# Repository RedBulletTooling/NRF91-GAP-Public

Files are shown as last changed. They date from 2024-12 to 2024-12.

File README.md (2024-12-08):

This is a project by Matthijs Vogel and Luc Pluimakers.

# Concept

NRF91 General Attack Platform, or GAP for short. The goal of the GAP module was to create a modular base from which we could design various types of listening devices. It serves as the central brain and communications hub, as well as the module that regulates power, eliminating the need for a complex PSU per purpose. We have decided to release this design to the public, as there is no benefit in keeping it private, and we believe it can add value to the public space.

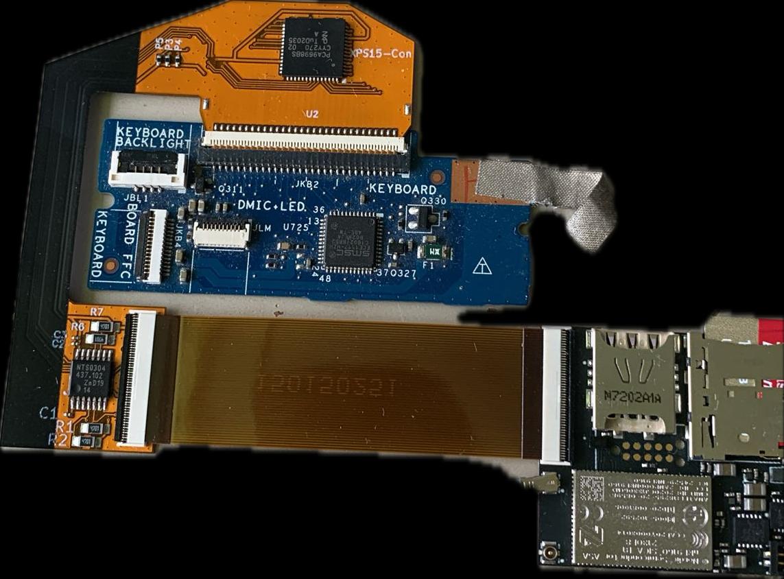
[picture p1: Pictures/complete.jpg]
complete


## NRF91GAP

The board itself. When designing it, the decision was made to make it thin—really thin. This is because most devices and locations have enough tolerance to hide something as long as it's thin enough. With this design, we achieved a thickness of 1.5mm. We used special LDOs (Low Dropout Regulators) with a wide operating range (20V to 1.8V)—one for powering the NRF91 and another for powering the external board, both outputting 5V. This way, it can be implemented in a car or connected directly to a laptop battery, making it an always-on system, regardless of whether the host machine is turned off. Perfect for pre-boot DMA injection! Almost all of the I/O of the NRF91 is directly connected to the ribbon cable, and they can be left floating if not needed. It uses a Tag-Connect cable for programming. It's a cool concept, and we hope some of you find a use for it!

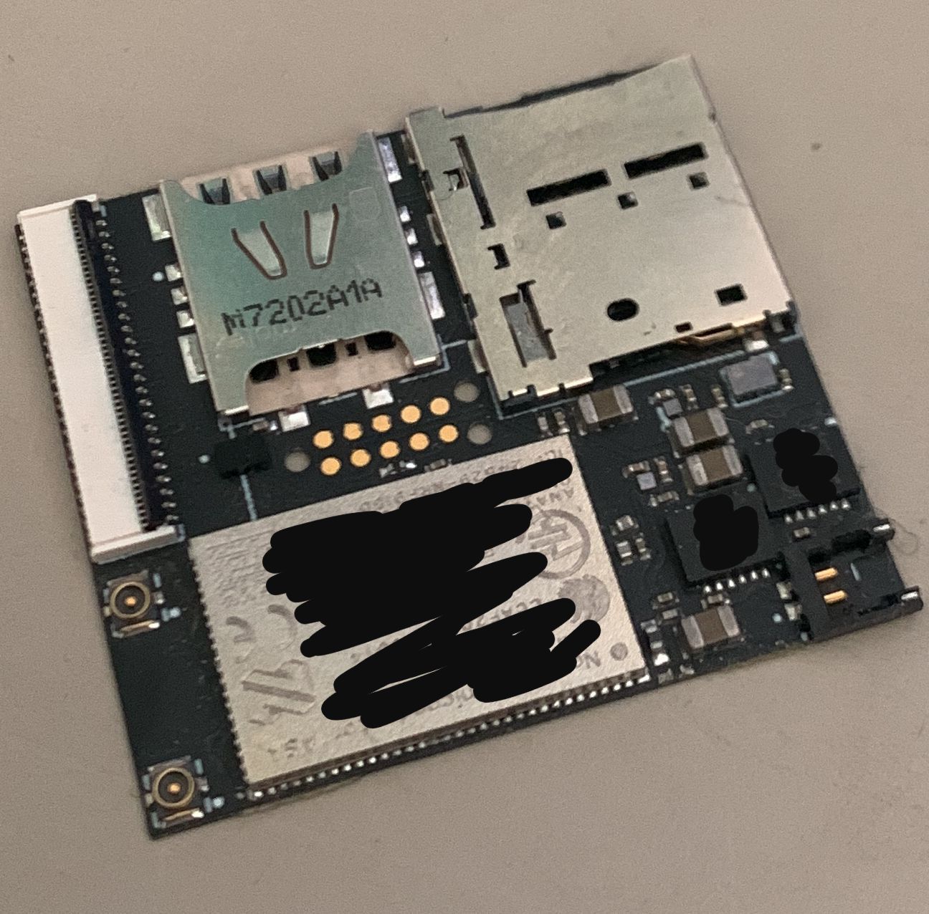
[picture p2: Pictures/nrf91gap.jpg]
nrf91gap


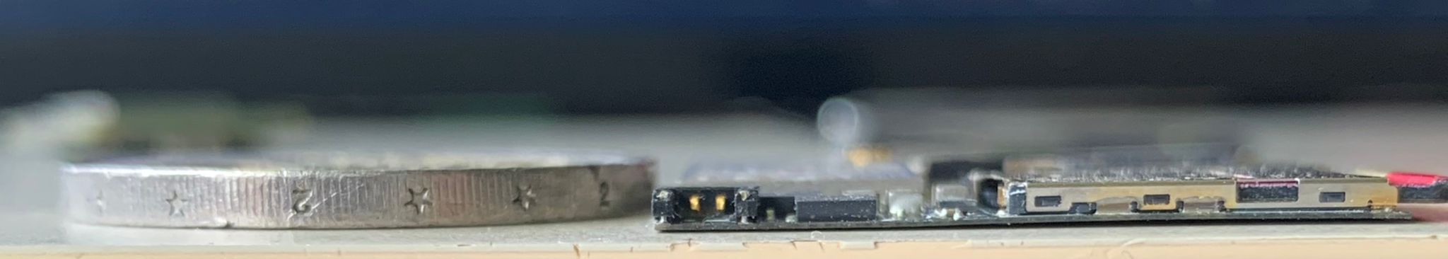
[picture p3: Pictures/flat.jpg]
flat


## Breakout Example

We have included an example breakout we designed for the NRF91GAP. The purpose of this board is to monitor the keystrokes of an XPS 15 laptop by sitting between the ribbon cable of the laptop's keyboard and the keyboard controller. It connects through a standard Molex ribbon cable, which coincides with the connector on the NRF91GAP. The breakout board itself is a flex PCB with specific rigid parts and is designed in such a way that it fits perfectly within the laptop. The flex PCB cable interfaces directly with a board, as if it were the ribbon cable. This demonstrates the capability of the NRF91GAP. You could do this with anything since it directly interfaces with the I/O ports of the NRF91 chip, and like what we did here, you can adjust voltages and translations on the breakout board.

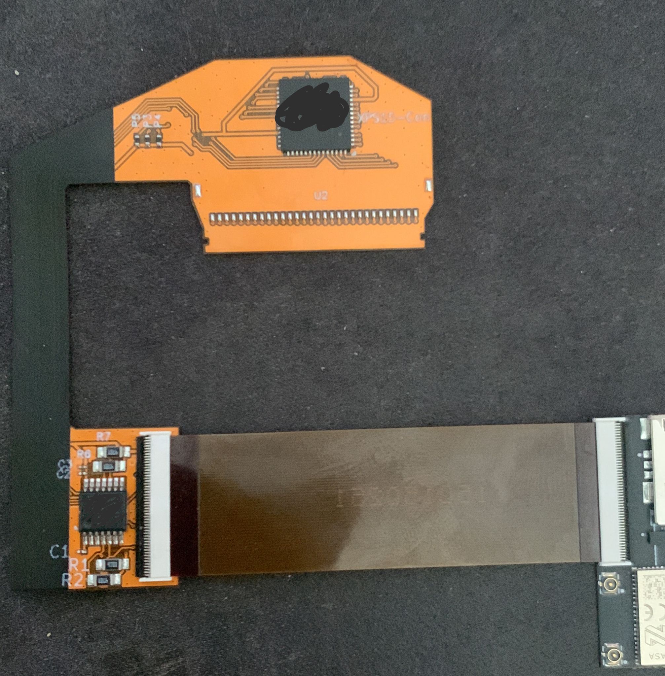
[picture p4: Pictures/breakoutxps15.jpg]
breakout


## Notes

This is a concept design. It is not yet in production. We are 80% confident that this will work as-is, but there are still some things to keep in mind:

1. The current version of the board has not been produced yet but is an improved version compared to the one in the pictures, as the earlier version had issues with BGA pads and a 0.3mm PCB thickness.
2. It is a 2-layer PCB with a relatively expensive design, as it heavily relies on thin traces, tented vias, and vias in pads.
3. The breakout board is a non-functional prototype. It needs revisions in multiple areas, but it shows the concept's capabilities.
4. The GAP board uses a special MHF4 antenna. If possible, use an MHF4L.

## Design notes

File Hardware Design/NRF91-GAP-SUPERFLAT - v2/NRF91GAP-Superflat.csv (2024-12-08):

Id | Designator | Behuizing | Hoeveelheid | Orientatie | Leverancier en ref
1 | J4 | DM3NWSFPEJ800 | 1 | DM3NW-SF-PEJ_800_
2 | NRF1 | XCVR_NRF9160-SICA-R | 1 | NRF9160-SICA-B1A-R
3 | SIMESDPROTECT1 | CM140203CP | 1 | CM1402-03CP
4 | R1 | RESC0603X26N | 1 | CR0201AFW-1001GLF
5 | J7 | 5047405100 | 1 | 504740-5100
6 | J6 | 1042240820 | 1 | 104224-0820
8 | J3,J2 | IPEX_20579-001E | 2 | 20579-001E
9 | J1 | 2121340002 | 1 | 212134-0002
10 | IC8,IC7,IC6,IC5 | BGA20C50P4X5_189X239X50 | 4 | TXB0108YZPR
11 | IC4 | BGA4C35P2X2_64X64X33 | 1 | TCR5RG33A,LF
12 | IC3,IC1 | SON50P300X400X80-13N-D | 2 | LT1763IDE-5#PBF
13 | IC2 | TCR5RG18ALF | 1 | TCR5RG18A,LF
14 | FL1 | BEADC1005X55N | 1 | MMZ1005S121HTD25
15 | C10,C9,C7,C5,C4,C1,1uF1 | CAPC0603X33N | 7 | GRM033C80J105ME05D
16 | C3,C2,47uF2,47uF1 | CAPC2012X95N | 4 | GRM219R60J476ME44D
17 | 4.7uF2,4.7uF1 | CAPC0603X55N | 2 | GRM035R60J475ME15D
18 | 15pF2,15pF1 | CAPC0603X33N | 2 | 885.392.004.002,00
19 | 10KOhm1 | RESC0603X26N | 1 | ERA-1AEB103C
20 | 100nF19,100nF15,100nF14,100nF13,100nF12,100nF11,100nF10,100nF9,100nF8,100nF7,100nF6,100nF5,100nF4,100nF3,100nF2,100nF1 | CAPC0603X33N | 16 | GRM033R60J104KE19J
21 | U1 | Texas_DSBGA-12_1.36x1.86mm_Layout3x4_P0.5mm | 1 | TXB0104YZT

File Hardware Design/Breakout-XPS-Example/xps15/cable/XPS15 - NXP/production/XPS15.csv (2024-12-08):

Id | Designator | Behuizing | Hoeveelheid | Orientatie | Leverancier en ref
1 | R7,R6,R2,R1 | ERA6A__0805_ | 4 | ERA-6ARW472V
2 | IC2 | SOP65P640X110-14N | 1 | NTS0304EPWJ
3 | C3 | CAPC0603X33N | 1 | GRM033R60J105MEA2D
4 | C2,C1 | CAPC0603X33N | 2 | GRM033R60J104KE19J
5 | J1 | 5047405100 | 1 | 504740-5100
6 | IC1 | QFN50P800X800X100-57N-D | 1 | PCA9698BS,118
7 | R5 | ERA2A__0402_ | 1 | ERA-2AED202X
8 | R4,R3 | ERA2A__0402_ | 2 | ERA-2ARC112X

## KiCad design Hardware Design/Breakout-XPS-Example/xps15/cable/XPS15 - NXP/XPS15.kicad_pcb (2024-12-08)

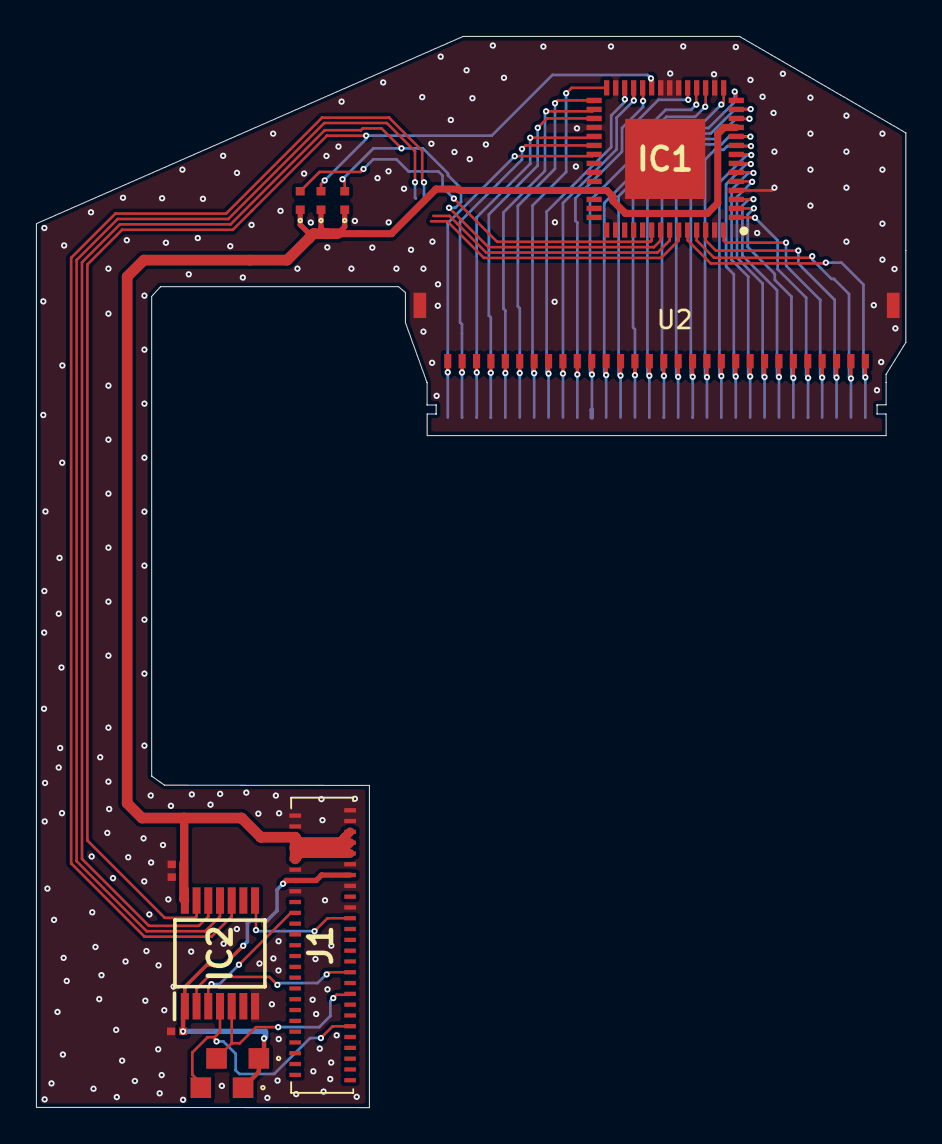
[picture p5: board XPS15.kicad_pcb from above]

Board: 2 copper layers, 48.3 x 59.5 mm, 13 parts (1 on the bottom side), 43 nets.

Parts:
C1, C2: GRM033R60J104KE19J; CAPC0603X33N
C3: GRM033R60J105MEA2D; CAPC0603X33N
IC1: PCA9698BS,118; QFN50P800X800X100-57N-D
IC2: NTS0304EPWJ; SOP65P640X110-14N
J1: 504740-5100; 5047405100
R1, R2: ERA-6ARW472V; ERA6A__0805_
R3, R4: ERA-2ARC112X; ERA2A__0402_
R5: ERA-2AED202X; ERA2A__0402_
U1: XPS-FLEX; Flex
U2: XPS15-Con; FPC-XPS15

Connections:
+1V8: C1.2, IC2.1, J1.38, J1.39, R1.1, R2.1
GND: C1.1, C2.2, C3.1, IC1.4, IC1.16, IC1.20, IC1.21, IC1.22, IC1.27, IC1.32, IC1.44, IC1.55, IC1.57, IC2.7, J1.33, J1.36, J1.37, J1.40, J1.41, J1.48, J1.49, J1.50, J1.51, U2.31, U2.32
INT: IC1.48, R5.2
OE: IC1.23, IC2.13, R3.2
OE-C: IC2.2, J1.21
OE-NTS: IC2.8, J1.31
SCL: IC1.51, IC2.10
SCL-C: IC2.5, J1.17, R1.2
SDA: IC1.50, IC2.11
SDA-C: IC2.4, J1.11, R2.2
VCC: C2.1, C3.2, IC1.11, IC1.39, IC2.14, J1.42, J1.43, J1.44, J1.45, J1.46, J1.47, R3.1, R4.1, R5.1
pin1: IC1.52, U1.1, U2.1
pin2: IC1.53, U1.2, U2.2
pin3: IC1.54, U1.3, U2.3
pin4: IC1.56, U1.4, U2.4
pin5: IC1.1, U1.5, U2.5
pin6: IC1.2, U1.6, U2.6
pin7: IC1.3, U1.7, U2.7
pin8: IC1.5, U1.8, U2.8
pin9: IC1.6, U1.9, U2.9
pin10: IC1.7, U1.10, U2.10
pin11: IC1.8, U1.11, U2.11
pin12: IC1.9, U1.12, U2.12
pin13: IC1.10, U1.13, U2.13
pin14: IC1.12, U1.14, U2.14
pin15: IC1.13, U1.15, U2.15
pin16: IC1.14, U1.16, U2.16
pin17: IC1.15, U1.17, U2.17
pin18: IC1.17, U1.18, U2.18
pin19: IC1.18, U1.19, U2.19
pin20: IC1.19, U1.20, U2.20
pin21: IC1.24, U1.21, U2.21
pin22: IC1.25, U1.22, U2.22
pin23: IC1.26, U1.23, U2.23
pin24: IC1.28, U1.24, U2.24
pin25: IC1.29, U1.25, U2.25
pin26: IC1.30, U1.26, U2.26
pin27: IC1.31, U1.27, U2.27
pin28: IC1.33, U1.28, U2.28
pin29: IC1.34, U1.29, U2.29
pin30: IC1.35, U1.30, U2.30
reset: IC1.49, IC2.12, R4.2
reset-C: IC2.3, J1.32

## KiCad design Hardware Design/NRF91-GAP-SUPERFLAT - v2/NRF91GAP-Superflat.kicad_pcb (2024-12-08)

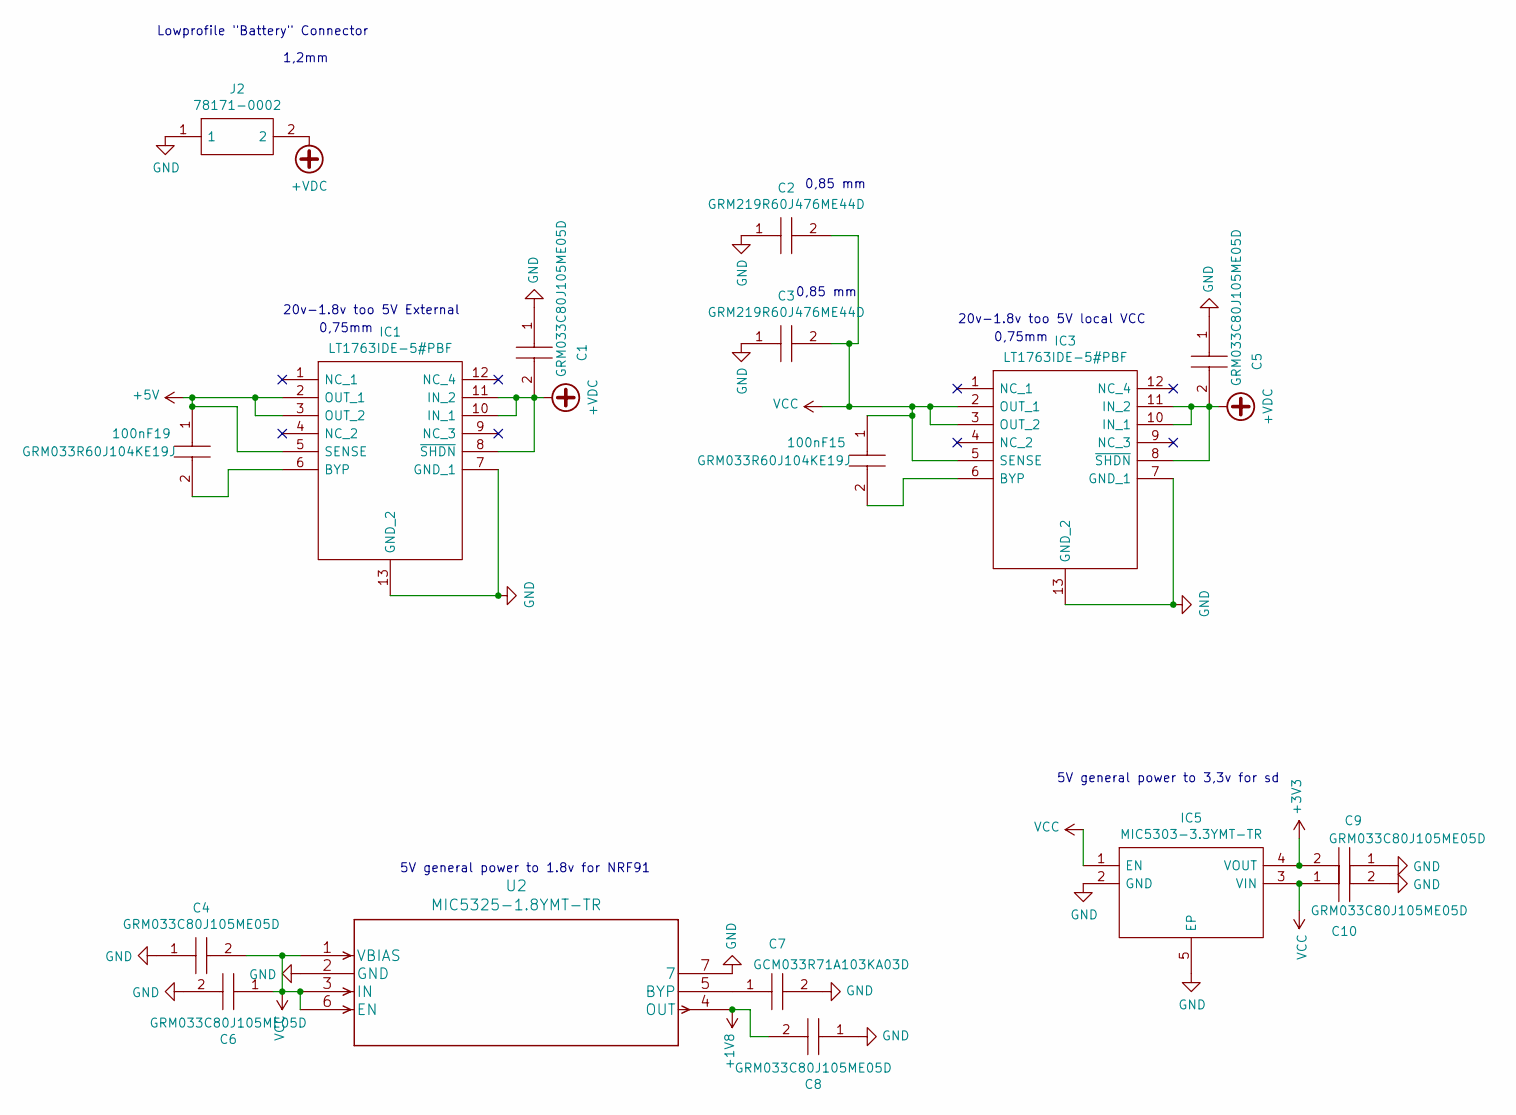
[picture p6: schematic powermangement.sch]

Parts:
100nF15, 100nF19: GRM033R60J104KE19J; CAPC0603X33N; Mouser Part Number 81-GRM033R60J104KE9J
C1, C4, C5, C6, C8, C9, C10: GRM033C80J105ME05D; CAPC0603X33N; Mouser Part Number 81-GRM033C80J105ME5D
C2, C3: GRM219R60J476ME44D; CAPC2012X95N; Mouser Part Number 81-GRM219R60J476ME4D
C7: GCM033R71A103KA03D; CAPC0603X33N; Mouser Part Number 81-GCM033R71A103KA3D
IC1, IC3: LT1763IDE-5#PBF; SON50P300X400X80-13N-D; Mouser Part Number 584-LT1763IDE-5#PBF
IC5: MIC5303-3.3YMT-TR; SON50P160X120X60-5N-D; Mouser Part Number MIC5303-3.3YMT-TR
J2: 78171-0002; Mouser Part Number 538-78171-0002
U2: MIC5325-1.8YMT-TR

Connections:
+1V8: C8.2, U2.4 (OUT); also elsewhere on the board
+3V3: C9.2, IC5.4 (VOUT); also elsewhere on the board
+5V: 100nF19.1, IC1.2 (OUT_1), IC1.3 (OUT_2), IC1.5 (SENSE); also elsewhere on the board
+VDC: C1.2, C5.2, IC1.8 (~SHDN), IC1.10 (IN_1), IC1.11 (IN_2), IC3.8 (~SHDN), IC3.10 (IN_1), IC3.11 (IN_2), J2.2
GND: C1.1, C2.1, C3.1, C4.1, C5.1, C6.2, C7.2, C8.1, C9.1, C10.2, IC1.7 (GND_1), IC1.13 (GND_2), IC3.7 (GND_1), IC3.13 (GND_2), IC5.2 (GND), IC5.5 (EP), J2.1, U2.2 (GND), U2.7; also elsewhere on the board
unnamed: 100nF15.2, IC3.6 (BYP)
unnamed: 100nF19.2, IC1.6 (BYP)
unnamed: C7.1, U2.5 (BYP)
VCC: 100nF15.1, C2.2, C3.2, C4.2, C6.1, C10.1, IC3.2 (OUT_1), IC3.3 (OUT_2), IC3.5 (SENSE), IC5.1 (EN), IC5.3 (VIN), U2.1 (VBIAS), U2.3 (IN), U2.6 (EN); also elsewhere on the board

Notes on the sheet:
Lowprofile "Battery" Connector
20v-1.8v too 5V External
5V general power to 1.8v for NRF91
5V general power to 3,3v for sd
1,2mm
20v-1.8v too 5V local VCC
0,75mm
0,85 mm

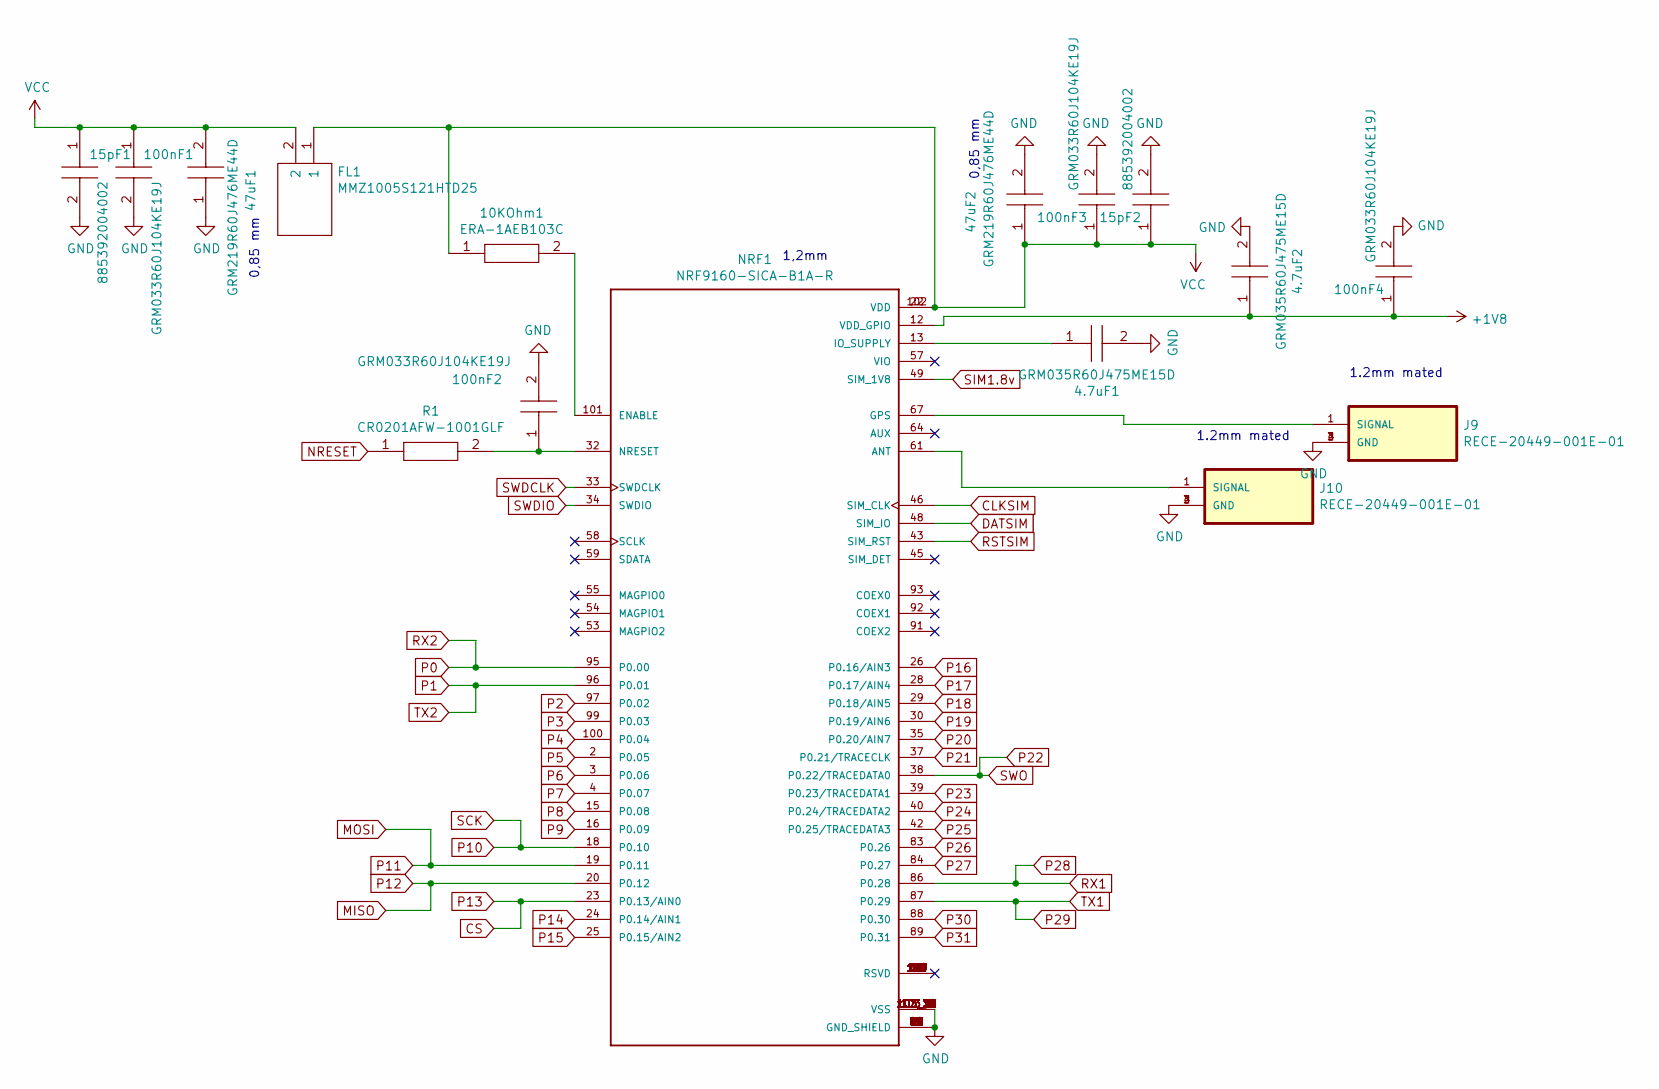
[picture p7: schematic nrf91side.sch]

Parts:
4.7uF1, 4.7uF2: GRM035R60J475ME15D; CAPC0603X55N; Mouser Part Number 81-GRM035R60J475ME5D
10KOhm1: ERA-1AEB103C; RESC0603X26N; Mouser Part Number 667-ERA-1AEB103C
15pF1, 15pF2: 885392004002; CAPC0603X33N; Mouser Part Number 710-885392004002
47uF1, 47uF2: GRM219R60J476ME44D; CAPC2012X95N; Mouser Part Number 81-GRM219R60J476ME4D
100nF1, 100nF2, 100nF3, 100nF4: GRM033R60J104KE19J; CAPC0603X33N; Mouser Part Number 81-GRM033R60J104KE9J
FL1: MMZ1005S121HTD25; BEADC1005X55N; Mouser Part Number 810-MMZ1005S121HTD25
J9, J10: RECE-20449-001E-01; CONN_RECE-20449-001E-01; PARTREV C
NRF1: NRF9160-SICA-B1A-R; XCVR_NRF9160-SICA-R
R1: CR0201AFW-1001GLF; RESC0603X26N; Mouser Part Number 652-CR0201AFW1001GLF

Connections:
+1V8: 4.7uF2.1, 100nF4.1, NRF1.12 (VDD_GPIO); also elsewhere on the board
CLKSIM: NRF1.46 (SIM_CLK); also elsewhere on the board
CS: NRF1.23 (P0.13/AIN0); also elsewhere on the board
DATSIM: NRF1.48 (SIM_IO); also elsewhere on the board
GND: 4.7uF1.2, 4.7uF2.2, 15pF1.2, 15pF2.2, 47uF1.1, 47uF2.2, 100nF1.2, 100nF2.2, 100nF3.2, 100nF4.2, J9.2 (GND), J9.3 (GND), J9.4 (GND), J10.2 (GND), J10.3 (GND), J10.4 (GND), NRF1.1 (GND_SHIELD), NRF1.5 (GND_SHIELD), NRF1.9 (GND_SHIELD), NRF1.14 (GND_SHIELD), NRF1.17 (GND_SHIELD), NRF1.21 (GND_SHIELD), NRF1.27 (GND_SHIELD), NRF1.31 (GND_SHIELD), NRF1.36 (GND_SHIELD), NRF1.41 (GND_SHIELD), NRF1.44 (GND_SHIELD), NRF1.47 (GND_SHIELD), NRF1.50 (GND_SHIELD), NRF1.52 (GND_SHIELD), NRF1.56 (GND_SHIELD), NRF1.60 (GND_SHIELD), NRF1.62 (GND_SHIELD), NRF1.63 (GND_SHIELD), NRF1.65 (GND_SHIELD), NRF1.66 (GND_SHIELD), NRF1.72 (GND_SHIELD), NRF1.74 (GND_SHIELD), NRF1.75 (GND_SHIELD), NRF1.76 (GND_SHIELD), NRF1.77 (GND_SHIELD), NRF1.78 (GND_SHIELD), NRF1.79 (GND_SHIELD), NRF1.80 (GND_SHIELD), NRF1.81 (GND_SHIELD), NRF1.82 (GND_SHIELD), NRF1.85 (GND_SHIELD), NRF1.90 (GND_SHIELD), NRF1.94 (GND_SHIELD), NRF1.98 (GND_SHIELD), NRF1.103_1 (VSS), NRF1.103_2 (VSS), NRF1.103_3 (VSS), NRF1.103_4 (VSS), NRF1.103_5 (VSS), NRF1.103_6 (VSS), NRF1.103_7 (VSS), NRF1.103_8 (VSS), NRF1.103_9 (VSS), NRF1.103_10 (VSS), NRF1.103_11 (VSS), NRF1.103_12 (VSS), NRF1.103_13 (VSS), NRF1.103_14 (VSS), NRF1.103_15 (VSS), NRF1.103_16 (VSS), NRF1.103_17 (VSS), NRF1.103_18 (VSS), NRF1.103_19 (VSS), NRF1.103_20 (VSS), NRF1.103_21 (VSS), NRF1.103_22 (VSS), NRF1.103_23 (VSS), NRF1.103_24 (VSS), NRF1.103_25 (VSS), NRF1.103_26 (VSS), NRF1.103_27 (VSS), NRF1.103_28 (VSS), NRF1.103_29 (VSS), NRF1.103_30 (VSS), NRF1.103_31 (VSS), NRF1.103_32 (VSS), NRF1.103_33 (VSS), NRF1.103_34 (VSS), NRF1.103_35 (VSS); also elsewhere on the board
MISO: NRF1.20 (P0.12); also elsewhere on the board
MOSI: NRF1.19 (P0.11); also elsewhere on the board
NRESET: R1.1; also elsewhere on the board
unnamed: 4.7uF1.1, NRF1.13 (IO_SUPPLY)
unnamed: 10KOhm1.2, NRF1.101 (ENABLE)
unnamed: 100nF2.1, NRF1.32 (NRESET), R1.2
unnamed: J9.1 (SIGNAL), NRF1.67 (GPS)
unnamed: J10.1 (SIGNAL), NRF1.61 (ANT)
unnamed: NRF1.6 (RSVD), NRF1.7 (RSVD), NRF1.8 (RSVD), NRF1.10 (RSVD), NRF1.11 (RSVD), NRF1.51 (RSVD), NRF1.68 (RSVD), NRF1.69 (RSVD), NRF1.70 (RSVD), NRF1.71 (RSVD), NRF1.73 (RSVD), NRF1.104 (RSVD), NRF1.105 (RSVD), NRF1.106 (RSVD), NRF1.107 (RSVD), NRF1.108 (RSVD), NRF1.109 (RSVD), NRF1.110 (RSVD), NRF1.111 (RSVD), NRF1.112 (RSVD), NRF1.113 (RSVD), NRF1.114 (RSVD), NRF1.115 (RSVD), NRF1.116 (RSVD), NRF1.117 (RSVD), NRF1.118 (RSVD), NRF1.119 (RSVD), NRF1.120 (RSVD), NRF1.121 (RSVD), NRF1.122 (RSVD), NRF1.123 (RSVD), NRF1.124 (RSVD), NRF1.125 (RSVD), NRF1.126 (RSVD), NRF1.127 (RSVD)
P0: NRF1.95 (P0.00); also elsewhere on the board
P1: NRF1.96 (P0.01); also elsewhere on the board
P2: NRF1.97 (P0.02); also elsewhere on the board
P3: NRF1.99 (P0.03); also elsewhere on the board
P4: NRF1.100 (P0.04); also elsewhere on the board
P5: NRF1.2 (P0.05); also elsewhere on the board
P6: NRF1.3 (P0.06); also elsewhere on the board
P7: NRF1.4 (P0.07); also elsewhere on the board
P8: NRF1.15 (P0.08); also elsewhere on the board
P9: NRF1.16 (P0.09); also elsewhere on the board
P10: NRF1.18 (P0.10); also elsewhere on the board
P14: NRF1.24 (P0.14/AIN1); also elsewhere on the board
P15: NRF1.25 (P0.15/AIN2); also elsewhere on the board
P16: NRF1.26 (P0.16/AIN3); also elsewhere on the board
P17: NRF1.28 (P0.17/AIN4); also elsewhere on the board
P18: NRF1.29 (P0.18/AIN5); also elsewhere on the board
P19: NRF1.30 (P0.19/AIN6); also elsewhere on the board
P20: NRF1.35 (P0.20/AIN7); also elsewhere on the board
P21: NRF1.37 (P0.21/TRACECLK); also elsewhere on the board
P22: NRF1.38 (P0.22/TRACEDATA0); also elsewhere on the board
P23: NRF1.39 (P0.23/TRACEDATA1); also elsewhere on the board
P24: NRF1.40 (P0.24/TRACEDATA2); also elsewhere on the board
P25: NRF1.42 (P0.25/TRACEDATA3); also elsewhere on the board
P26: NRF1.83 (P0.26); also elsewhere on the board
P27: NRF1.84 (P0.27); also elsewhere on the board
P28: NRF1.86 (P0.28); also elsewhere on the board
P29: NRF1.87 (P0.29); also elsewhere on the board
P30: NRF1.88 (P0.30); also elsewhere on the board
P31: NRF1.89 (P0.31); also elsewhere on the board
RSTSIM: NRF1.43 (SIM_RST); also elsewhere on the board
SIM1.8v: NRF1.49 (SIM_1V8); also elsewhere on the board
SWDCLK: NRF1.33 (SWDCLK); also elsewhere on the board
SWDIO: NRF1.34 (SWDIO); also elsewhere on the board
VCC: 10KOhm1.1, 15pF1.1, 15pF2.1, 47uF1.2, 47uF2.1, 100nF1.1, 100nF3.1, FL1.1, FL1.2, NRF1.22 (VDD), NRF1.102 (VDD); also elsewhere on the board

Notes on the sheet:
0,85 mm
1,2mm
1.2mm mated

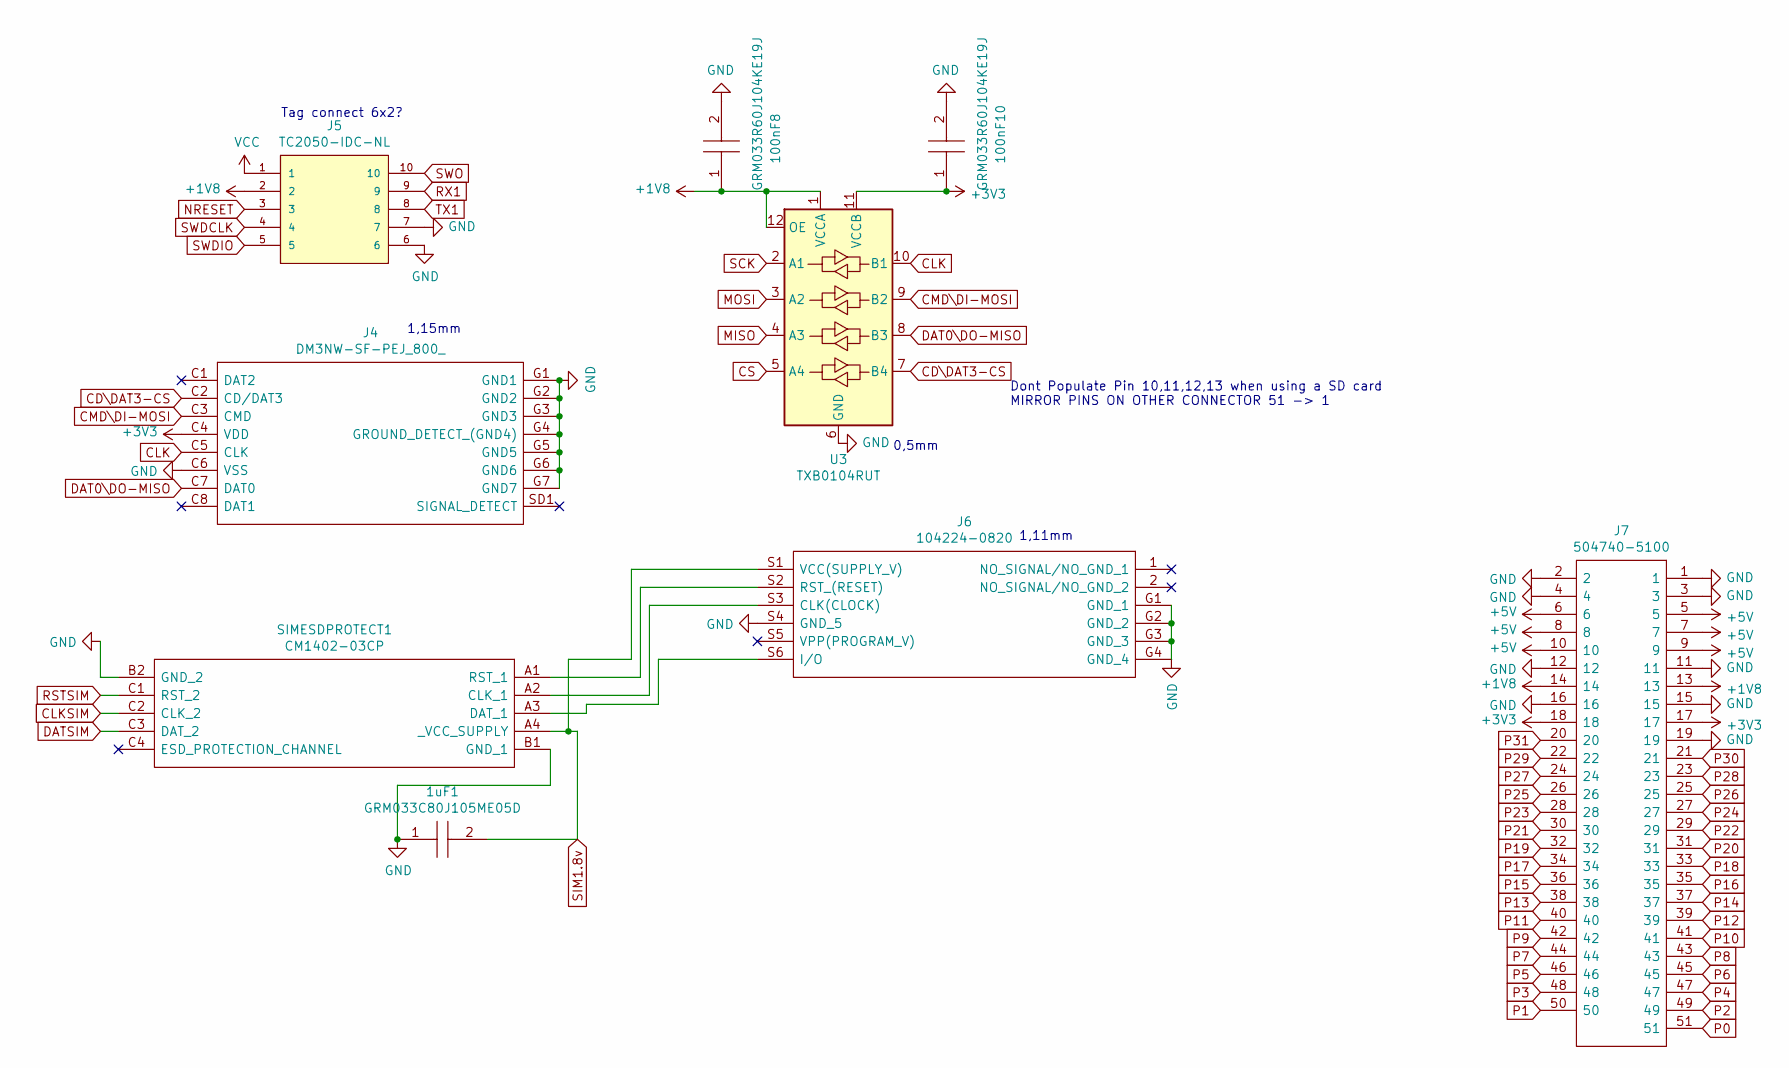
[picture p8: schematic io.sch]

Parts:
1uF1: GRM033C80J105ME05D; CAPC0603X33N; Mouser Part Number 81-GRM033C80J105ME5D
100nF8, 100nF10: GRM033R60J104KE19J; CAPC0603X33N; Mouser Part Number 81-GRM033R60J104KE9J
J4: DM3NW-SF-PEJ_800_; DM3NWSFPEJ800; Mouser Part Number 798-DM3NW-SF-PEJ800
J5: TC2050-IDC-NL; TAG-CONNECT_TC2050-IDC-NL; PARTREV A
J6: 104224-0820; 1042240820; Mouser Part Number 538-104224-0820
J7: 504740-5100; 5047405100; Mouser Part Number 538-504740-5100
SIMESDPROTECT1: CM1402-03CP; CM140203CP; Mouser Part Number 748-CM1402-03CP
U3: TXB0104RUT; Texas_R_PUQFN-N12

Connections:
+1V8: 100nF8.1, J5.2, J7.13, J7.14, U3.1 (VCCA), U3.12 (OE); also elsewhere on the board
+3V3: 100nF10.1, J4.C4 (VDD), J7.17, J7.18, U3.11 (VCCB); also elsewhere on the board
+5V: J7.5, J7.6, J7.7, J7.8, J7.9, J7.10; also elsewhere on the board
CD\DAT3-CS: J4.C2 (CD/DAT3), U3.7 (B4)
CLK: J4.C5 (CLK), U3.10 (B1)
CLKSIM: SIMESDPROTECT1.C2 (CLK_2); also elsewhere on the board
CMD\DI-MOSI: J4.C3 (CMD), U3.9 (B2)
CS: J7.38, U3.5 (A4); also elsewhere on the board
DAT0\DO-MISO: J4.C7 (DAT0), U3.8 (B3)
DATSIM: SIMESDPROTECT1.C3 (DAT_2); also elsewhere on the board
GND: 1uF1.1, 100nF8.2, 100nF10.2, J4.C6 (VSS), J4.G1 (GND1), J4.G2 (GND2), J4.G3 (GND3), J4.G4 (GROUND_DETECT_(GND4)), J4.G5 (GND5), J4.G6 (GND6), J4.G7 (GND7), J5.6, J5.7, J6.G1 (GND_1), J6.G2 (GND_2), J6.G3 (GND_3), J6.G4 (GND_4), J6.S4 (GND_5), J7.1, J7.2, J7.3, J7.4, J7.11, J7.12, J7.15, J7.16, J7.19, SIMESDPROTECT1.B1 (GND_1), SIMESDPROTECT1.B2 (GND_2), U3.6 (GND); also elsewhere on the board
MISO: J7.39, U3.4 (A3); also elsewhere on the board
MOSI: J7.40, U3.3 (A2); also elsewhere on the board
NRESET: J5.3; also elsewhere on the board
unnamed: J6.S2 (RST_(RESET)), SIMESDPROTECT1.A1 (RST_1)
unnamed: J6.S3 (CLK(CLOCK)), SIMESDPROTECT1.A2 (CLK_1)
unnamed: J6.S6 (I/O), SIMESDPROTECT1.A3 (DAT_1)
P0: J7.51; also elsewhere on the board
P1: J7.50; also elsewhere on the board
P2: J7.49; also elsewhere on the board
P3: J7.48; also elsewhere on the board
P4: J7.47; also elsewhere on the board
P5: J7.46; also elsewhere on the board
P6: J7.45; also elsewhere on the board
P7: J7.44; also elsewhere on the board
P8: J7.43; also elsewhere on the board
P9: J7.42; also elsewhere on the board
P10: J7.41, U3.2 (A1); also elsewhere on the board
P14: J7.37; also elsewhere on the board
P15: J7.36; also elsewhere on the board
P16: J7.35; also elsewhere on the board
P17: J7.34; also elsewhere on the board
P18: J7.33; also elsewhere on the board
P19: J7.32; also elsewhere on the board
P20: J7.31; also elsewhere on the board
P21: J7.30; also elsewhere on the board
P22: J5.10, J7.29; also elsewhere on the board
P23: J7.28; also elsewhere on the board
P24: J7.27; also elsewhere on the board
P25: J7.26; also elsewhere on the board
P26: J7.25; also elsewhere on the board
P27: J7.24; also elsewhere on the board
P28: J5.9, J7.23; also elsewhere on the board
P29: J5.8, J7.22; also elsewhere on the board
P30: J7.21; also elsewhere on the board
P31: J7.20; also elsewhere on the board
RSTSIM: SIMESDPROTECT1.C1 (RST_2); also elsewhere on the board
SIM1.8v: 1uF1.2, J6.S1 (VCC(SUPPLY_V)), SIMESDPROTECT1.A4 (_VCC_SUPPLY); also elsewhere on the board
SWDCLK: J5.4; also elsewhere on the board
SWDIO: J5.5; also elsewhere on the board
VCC: J5.1; also elsewhere on the board

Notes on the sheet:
0,5mm
Tag connect 6x2?
1,15mm
1,11mm
Dont Populate Pin 10,11,12,13 when using a SD card MIRROR PINS ON OTHER CONNECTOR 51 -> 1

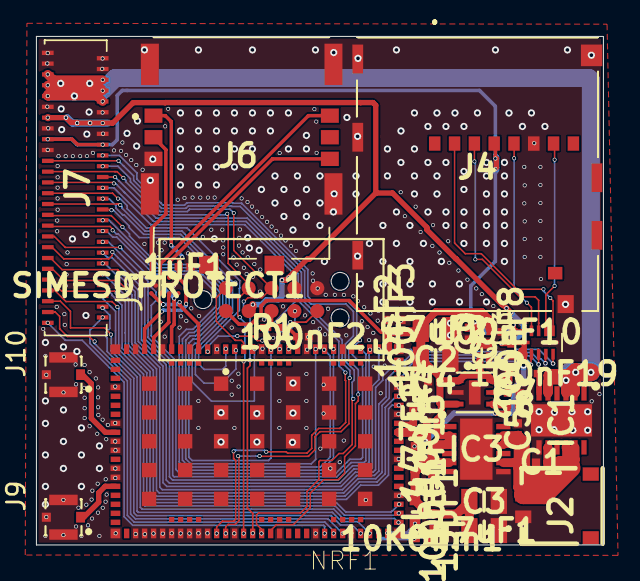
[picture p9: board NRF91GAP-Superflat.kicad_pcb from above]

Board: 2 copper layers, 31.5 x 28.2 mm, 41 parts (0 on the bottom side), 61 nets.
